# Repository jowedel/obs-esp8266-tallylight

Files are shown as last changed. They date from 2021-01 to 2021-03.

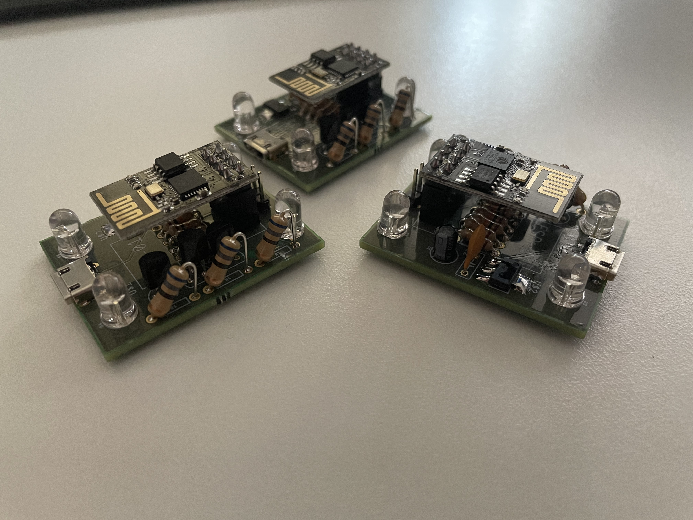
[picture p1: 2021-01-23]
pictures/boards_1.jpeg

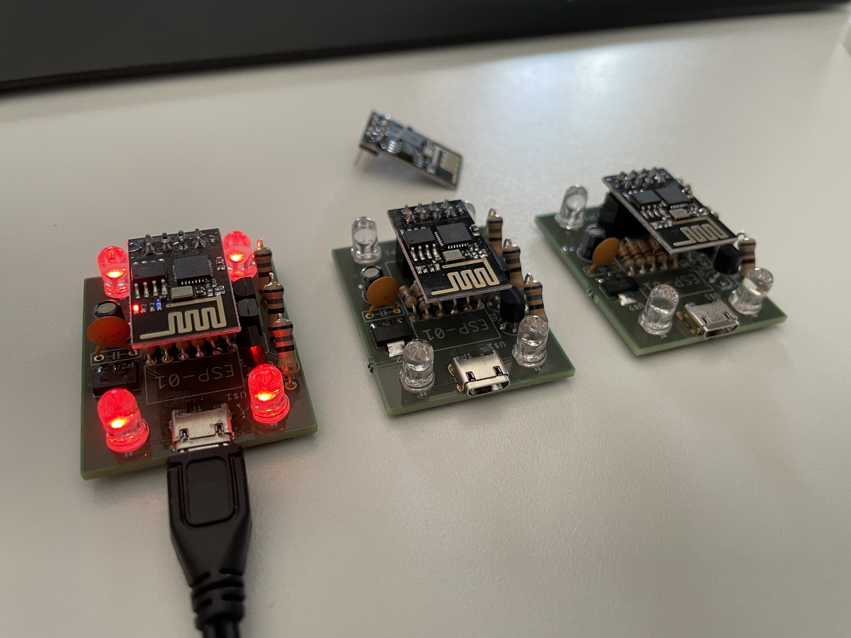
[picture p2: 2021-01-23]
pictures/boards2.jpeg

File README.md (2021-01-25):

# obs-esp8266-tallylight
Build small WIFI enabled tallylights that work with the [obs-websocket](https://github.com/Palakis/obs-websocket) plugin.
The tallylight looks for a substring in the current scene name and when it matches it will light up red. Also works with the preview in studio mode (green light).

## Hardware
I used the esp01 module, but other esp modules should work too. You can build the circuit on perfboard, but if you want a clean and small package you can manufacture a pcb with the gerberfiles.

### Assembly
Use the partslist.txt and schematic.png for reference. I find it the easiest to start with the smd components. First I pre tin the pads and then carefully solder on the USB connector. Since we only need power, you only need to solder on the two outer pins. Be carefull that you don't make any shotcircuits. Next solder on the LEDs, again be careful not to cause any shortcircuits. After that check with a multi meter for shortcircuits. Now you can solder on the rest of the components.

## Software
The Programm is far from finished, my C/C++ skills are a little rusty :). Right now you need to specify the fixed IP adress of your obs machine and authentication isn't working.

### OBS Setup
Install the [obs-websocket](https://github.com/Palakis/obs-websocket) plugin.
I recommend that you set the IP of your pc that is running OBS to a static one. Otherwise you have to reflash the esp every time your pc gets a different ip from DHCP.
Important: Don't activate athentication the tallylights currently don't support it!

### ESP8266 Setup
You need to setup the Arduino IDE with ESP8266 support. Check the [esp8266/Arduino](https://github.com/esp8266/Arduino) repo for details.
You'll also need the [ESP8266-Websocket](https://github.com/morrissinger/ESP8266-Websocket) and [ArduinoJson](https://arduinojson.org) librarys.

Next you need to edit the #defines to configure the program:
| Name | Description |
| --- | --- |
| WIFI_SSID | Your WIFI SSID |
| WIFI_PASS | The passfrase of your WIFI |
| OBS_WEBSOCKET_IP | Here you need to enter the IP of the computer that obs is running on |
| OBS_WEBSOCKET_PORT | Here you can specify the port. 4444 is the obs-websocket default port |
| OBS_WEBSOCKET_PASS | This is currently not working |
| OBS_SCENE_NAME | Here you need to enter the Substring that the tallylight should listen for. As an Example "Cam 1"|

Now you can flash the programm onto the esp and it should connect to your WIFI and OBS instance.

### Errors
I added some error codes:
| Name | Description |
| --- | --- |
| Blue constant flashing | The tallylight tries to connect to your WIFI |
| Blue burst flashing | The tallylight is connected to your WIFI but can't connect to OBS |
| Orange | Part of the disabled authentication, should not happen :D |

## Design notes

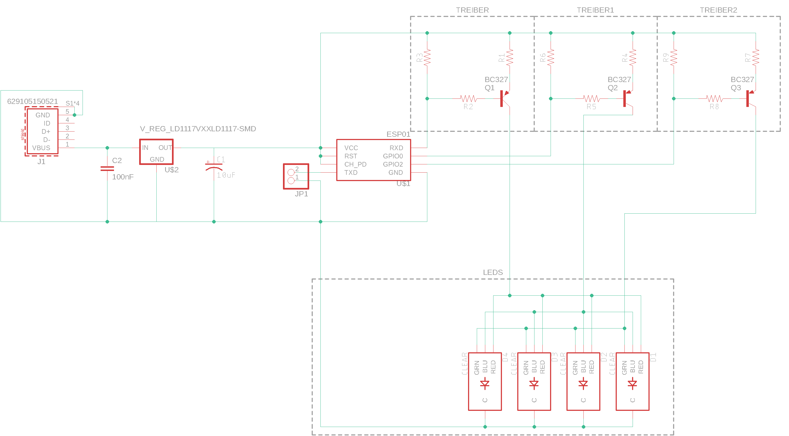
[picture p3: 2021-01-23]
schematic.png

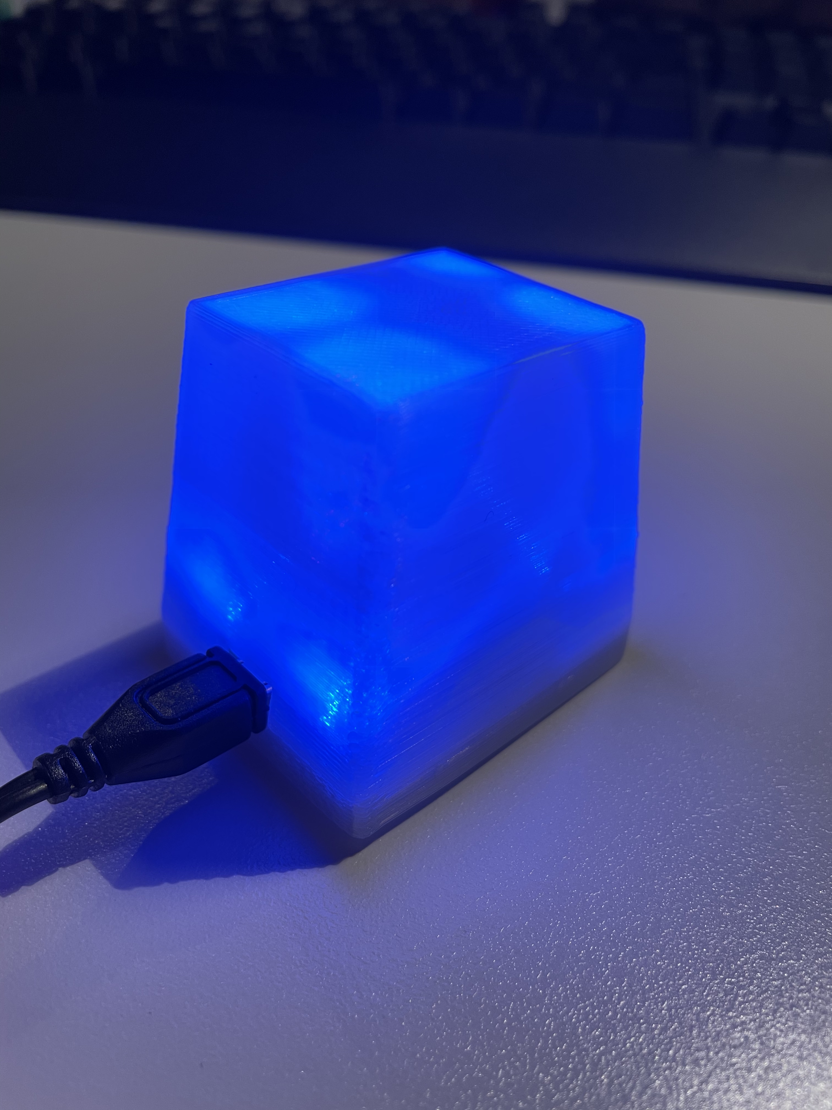
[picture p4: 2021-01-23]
pictures/tallylight.jpeg

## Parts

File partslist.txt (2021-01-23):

Partslist:

1x		J1 			Würth Micro-USB 629105150521		https://www.conrad.de/de/p/micro-usb-steckverbinder-serie-wr-com-buchse-einbau-vertikal-smt-629105150521-wuerth-elektronik-inhalt-1-st-1898830.html
1x		JP1			1x2 Pin Header Male			https://www.conrad.de/de/p/connfly-stiftleiste-standard-anzahl-reihen-1-polzahl-je-reihe-40-ds1021-1-40sf11-1-st-1390109.html
1x		(ESP01)			2x4 Pin Header Female			https://www.conrad.de/de/p/econ-connect-buchsenleiste-standard-anzahl-reihen-2-polzahl-je-reihe-4-blg2x4-1-st-1492287.html

1x		U1			ESP8266-01 Module
1x		U2			3.3V Voltage Regulator LD1117 (SMD)	https://www.conrad.de/de/p/stmicroelectronics-ld1117s33ctr-spannungsregler-linear-sot-223-positiv-fest-800-ma-1184700.html

3x		Q1			BC327 PNP Transistor			https://www.conrad.de/de/p/diotec-transistor-bjt-diskret-bc327-40bk-to-92-anzahl-kanaele-1-pnp-140535.html

1x		C1			10uF Condesator				https://www.conrad.de/de/p/yageo-s5025m0010b1f-0405-elektrolyt-kondensator-radial-bedrahtet-1-5-mm-10-f-25-v-20-x-h-4-mm-x-5-mm-1-st-445591.html
1x		C2			100nF Ceramic-Condensator			https://www.conrad.de/de/p/tru-components-tc-k100nf5-keramik-kondensator-tht-100-nf-50-v-20-1-st-1589524.html

6x		R2,R3,R5,R6,R8,R9	Resistor 10kΩ				https://www.conrad.de/de/p/yageo-cfr-25jt-52-10k-kohleschicht-widerstand-10-k-axial-bedrahtet-0207-0-25-w-5-1-st-1417697.html
3x		R1,R4,R7			Resistor 68Ω				https://www.conrad.de/de/p/weltron-kohleschicht-widerstand-68-axial-bedrahtet-0411-0-5-w-5-1-st-405116.html

4x		D1,D2,D3,D4		RGB LED Common Cathode

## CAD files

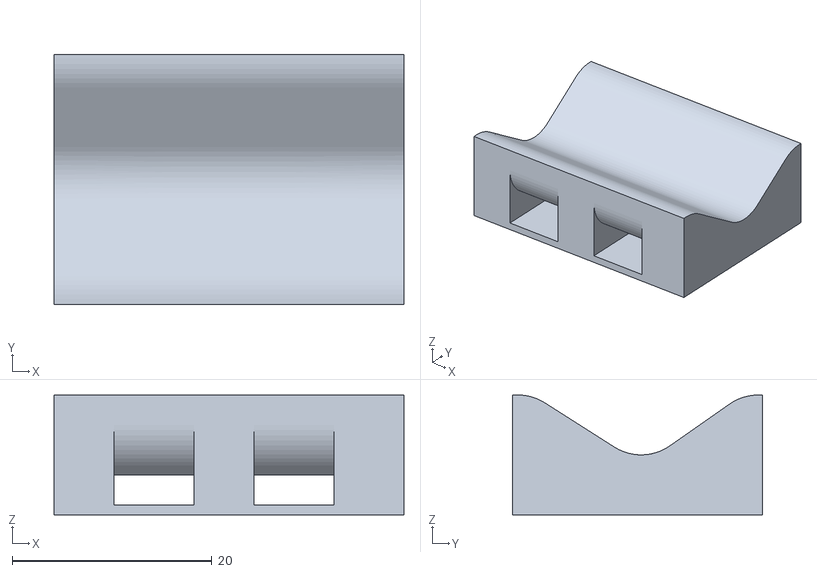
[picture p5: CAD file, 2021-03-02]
tally_ziptie_mount v1.stl
35.0 x 25.0 x 12.0

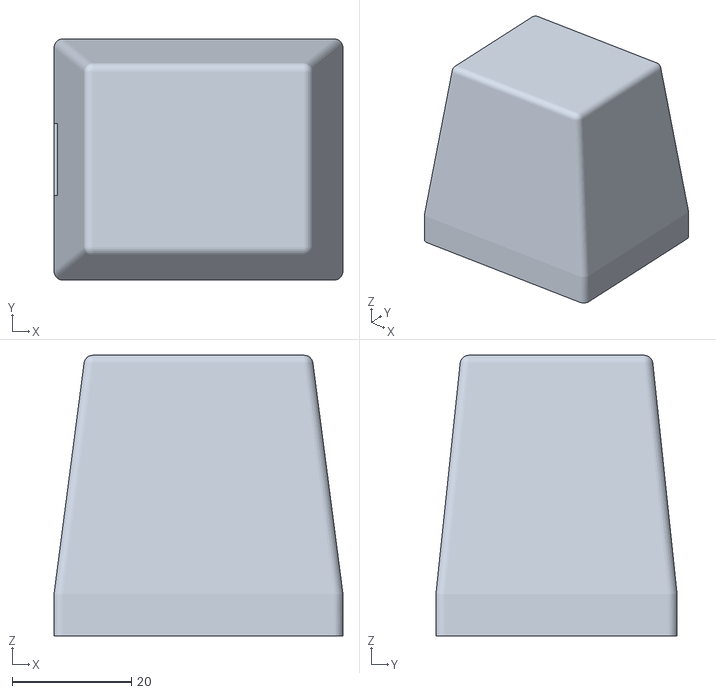
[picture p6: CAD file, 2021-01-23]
obs-esp8266-tallylight-top-V1_1.stl
48.4 x 40.4 x 47.0

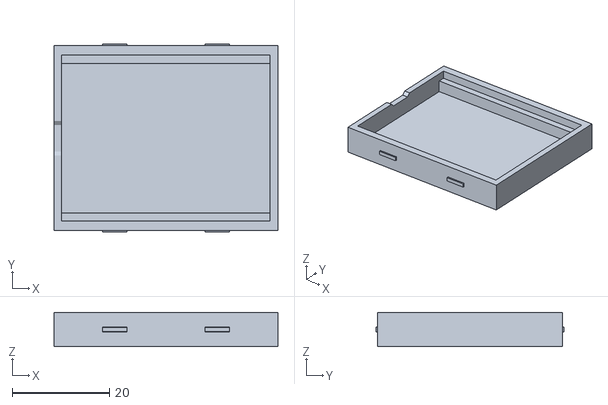
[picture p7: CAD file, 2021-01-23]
obs-esp8266-tallylight-bottom-V1_1.stl
46.0 x 38.7 x 7.00

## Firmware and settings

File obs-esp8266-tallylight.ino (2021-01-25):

#include <Arduino.h>

#include <ESP8266WiFi.h>
#include <ESP8266WiFiMulti.h>

#include <WebSocketsClient.h>

/*
#include <Hash.h>
#include <ESPCrypto.h>
#include <base64.h>
*/

#include <ArduinoJson.h>

ESP8266WiFiMulti WiFiMulti;
WebSocketsClient webSocket;

#define LED_RED 3
#define LED_GREEN 2
#define LED_BLUE 0

#define WIFI_SSID "YOUR-SSID-HERE"
#define WIFI_PASS "YOUR-WIFI-PASSWORD"
#define OBS_WEBSOCKET_IP "192.168.X.X" //Add OBS IP
#define OBS_WEBSOCKET_PORT 4444
#define OBS_WEBSOCKET_PASS "CURRENTLY NOT WORKING"
#define OBS_SCENE_NAME "SCENE-SUBSTRING" //"Cam 1"

boolean authRequired = false;
boolean checkAuth = true;
boolean connected = false;
long messageIdCounter = 2;
boolean redLedStatus = 1;
boolean greenLedStatus = 1;

void webSocketEvent(WStype_t type, uint8_t * payload, size_t length) {

	switch(type) {
		case WStype_DISCONNECTED:
      connected = false;
      redLedStatus = 1;
      greenLedStatus = 1;
      digitalWrite(LED_GREEN, 1);
      digitalWrite(LED_RED, 1);
      digitalWrite(LED_BLUE, 0);
      delay(100);
      digitalWrite(LED_BLUE, 1);
      delay(100);
      digitalWrite(LED_BLUE, 0);
      delay(100);
      digitalWrite(LED_BLUE, 1);
      delay(100);
      digitalWrite(LED_BLUE, 0);
      delay(100);
      digitalWrite(LED_BLUE, 1);
      delay(100);
      digitalWrite(LED_BLUE, 0);
			break;
      
		case WStype_CONNECTED:
      connected = true;
      digitalWrite(LED_GREEN, 1);
      digitalWrite(LED_RED, 1);
      digitalWrite(LED_BLUE, 1);
			break;
      
		case WStype_TEXT: {
      DynamicJsonDocument resDoc(4069);
       // Deserialize the JSON document
      DeserializationError error = deserializeJson(resDoc, payload);

      // Test if parsing succeeds.
      if (error) {
        return;
      }
      
      String messageId = resDoc["message-id"];
      if(messageId == "1"){
        checkAuth = false;
        authRequired = resDoc["authRequired"];

        /*
        USE_SERIAL.printf("DEBUG 1");
        SHA256 hasher;
        byte shaResult[SHA256_SIZE];
        
        USE_SERIAL.printf("DEBUG 2");
          
        String salt = resDoc["salt"];
        String challenge = resDoc["challenge"];
        
        USE_SERIAL.printf("DEBUG 3");
        
        String secretString = OBS_WEBSOCKET_PASS + salt;
        int strLength = secretString.length();
        char* secretCharArr;
        secretString.toCharArray(secretCharArr, strLength);

        USE_SERIAL.printf("DEBUG 4");
        
        hasher.doUpdate(secretCharArr);
        hasher.doFinal(shaResult);
        
        USE_SERIAL.printf("DEBUG 5");
        
        String result = (char*) shaResult;
        String secret = base64::encode(result + challenge);
        strLength = secret.length();
        char* secretArr;
        secret.toCharArray(secretArr, strLength);
        hasher.doUpdate(secretArr);
        hasher.doFinal(shaResult);
        result = (char*) shaResult;
        String authResponse = base64::encode(result);

        StaticJsonDocument<512> responseDoc;
        responseDoc["request-type"] = "Authenticate";
        responseDoc["message-id"] = messageIdCounter++;
        responseDoc["auth"] = authResponse;
        String responseBody;        
        webSocket.sendTXT(responseBody); */    
      }
      else{
        String updateType = resDoc["update-type"];
        if(updateType == "SwitchScenes"){
          String sceneName = resDoc["scene-name"];
          if(sceneName.indexOf(OBS_SCENE_NAME) >= 0){
            redLedStatus = 0;
            return;
          }
          redLedStatus = 1;
        }

        if(updateType == "PreviewSceneChanged"){
          String sceneName = resDoc["scene-name"];
          if(sceneName.indexOf(OBS_SCENE_NAME) >= 0){
            greenLedStatus = 0;
            return;
          }
          greenLedStatus = 1;
        }
      }
			break;
		}
      
    case WStype_ERROR:
      break;
      
    case WStype_PING:
        // pong will be send automatically
        break;
        
    case WStype_PONG:
        // answer to a ping we send
        break;
    }

}

void setup() {
  pinMode(LED_RED, OUTPUT);
  pinMode(LED_GREEN, OUTPUT);
  pinMode(LED_BLUE, OUTPUT);
  digitalWrite(LED_RED, 1);
  digitalWrite(LED_GREEN, 1);
  digitalWrite(LED_BLUE, 1);

  //Wait for boot
	delay(4000);

	WiFiMulti.addAP(WIFI_SSID, WIFI_PASS);

	//WiFi.disconnect();
	while(WiFiMulti.run() != WL_CONNECTED) {
		digitalWrite(LED_RED, 1);
    digitalWrite(LED_GREEN, 1);
    digitalWrite(LED_BLUE, 0);
    Serial.print(".");
    delay(250);
    digitalWrite(LED_BLUE, 1);
    Serial.print(".");
    delay(250);
	}
  digitalWrite(LED_BLUE, 1);

	// server address, port and URL
	webSocket.begin(OBS_WEBSOCKET_IP, OBS_WEBSOCKET_PORT, "/");

	// event handler
	webSocket.onEvent(webSocketEvent);

	// try every 5000ms again if connection has failed
	webSocket.setReconnectInterval(5000);
  
  // start heartbeat (optional)
  // ping server every 15000 ms
  // expect pong from server within 3000 ms
  // consider connection disconnected if pong is not received 2 times
  webSocket.enableHeartbeat(15000, 3000, 2);

  delay(5000);
}

void loop() {
	webSocket.loop();

  if(connected){
    if(!authRequired){
      if(checkAuth){
        webSocket.sendTXT("{\"request-type\":\"GetAuthRequired\",\"message-id\":\"1\"}");
      }
      if(redLedStatus == 0){
        digitalWrite(LED_RED, redLedStatus);
        digitalWrite(LED_GREEN, 1);
      }
      else{
        digitalWrite(LED_RED, redLedStatus);
        digitalWrite(LED_GREEN, greenLedStatus);
      }
    }
    else{
      for(int i=0; i<15; i++){
        digitalWrite(LED_GREEN, 1);
        digitalWrite(LED_RED, 0);
        delay(500);
        digitalWrite(LED_GREEN, 0);
        digitalWrite(LED_RED, 1);
        delay(500);
      }
      authRequired = false;
      checkAuth = true;
    }
  }
}

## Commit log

2021-01-25 [BugFix] fix json deserialisation error with complex scenes
    [obs-esp8266-tallylight.ino]
2021-03-02 [feature] add ziptie mount
    [tally_ziptie_mount v1.stl]
